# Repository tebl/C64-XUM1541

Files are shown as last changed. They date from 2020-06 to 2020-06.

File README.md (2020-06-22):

# C64 XUM1541

The thing about old 5 1/4 inch floppies is that no matter the way they are stored, they are inherently in a constant decay until they're all disolved into nostalgia and tears. Because of that I wanted to archive my private collection of less than original floppy disks (I didn't know any better and I had a hard time being able to even afford empty disks). Anyway, I came across an interesting [blog-post](https://myoldcomputer.nl/commodore-64/xum1541-promicro/) where a dedicated superfan used an Arduino Pro Micro to connect the drive directly to a modern computer, allowing a disk to be copied to a D64-file within a minute!

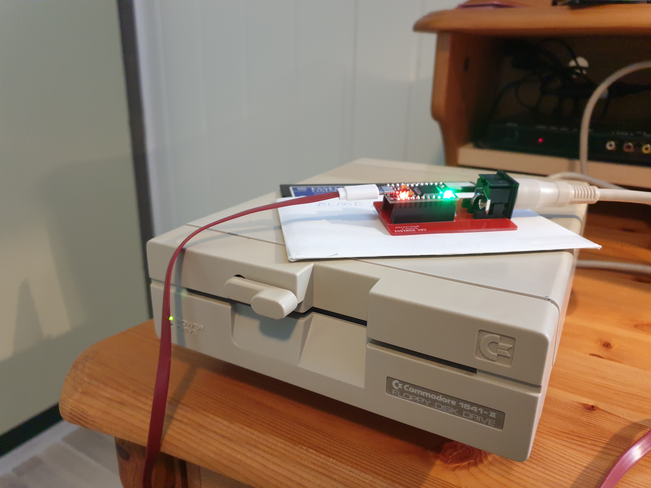
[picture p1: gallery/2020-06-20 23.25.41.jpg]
XUM1541


There are more professional solutions out there with a lot more features, but I wanted the simplest version of it all without actually soldering wires myself - so I threw together a simple PCB with the footprints matching parts I already had laying around in my parts-bin from building my Pi1541 module.

## Building the module
The module only consists of a handful of components, so just enure that get the components matching the BOM listed at the bottom of this page and solder it all together (component counts in parenthesis are not needed for a minimal build). The PCB may seem somewhat oversized for what it is, the reason for this is that I wanted it to fit into one of the 70x45x30mm electronic project boxes - when doing so you'd also install the power LED listed as an optional component, but bent out toward the side so that you can see it inside the box.

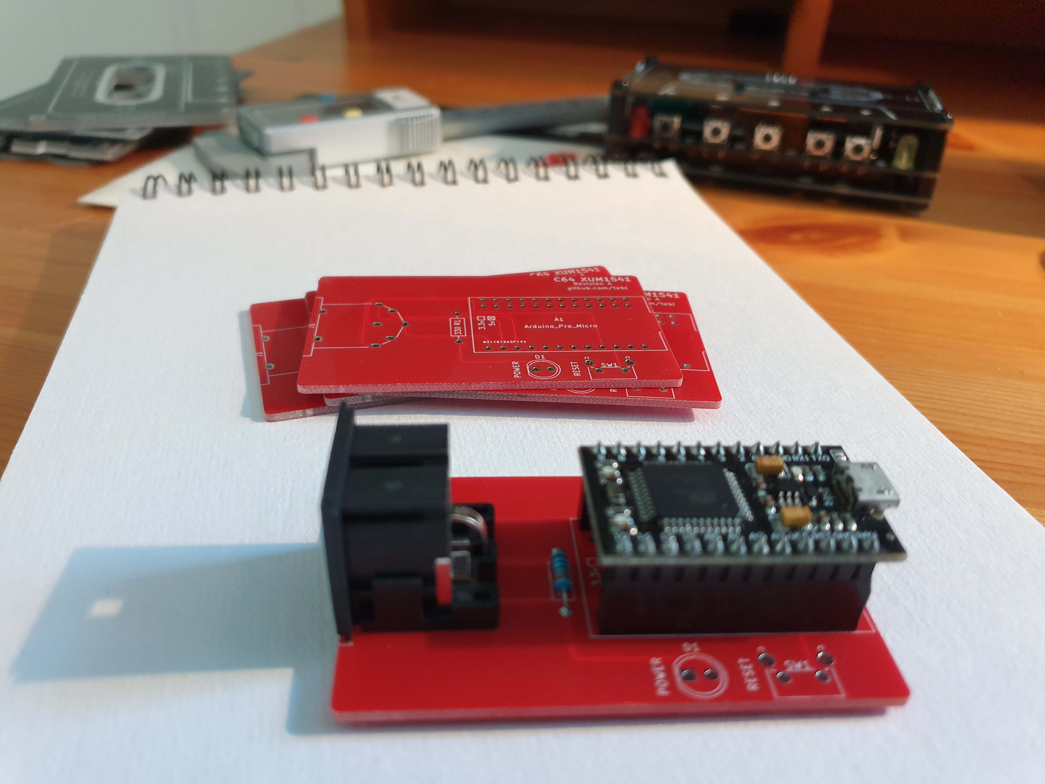
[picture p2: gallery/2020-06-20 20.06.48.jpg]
Module PCB


I you're building more than one of these, you probably won't need to install the reset switch on more than one of them (it is used when initially flashing the Arduino Pro Micro).

## Using the module
Using the actual module is a chapter unto itself, so I've put together a separate [firmware installation document](https://github.com/tebl/C64-XUM1541/blob/master/documentation/firmware.md) describing how to flash the Arduino Pro Micro with the correct firmware as well as set it up with the OpenCBM software for use on a Windows 10 computer. If you're on a different platform, you'll have to look up those guides separately as I only have the one laptop.

There is also an extensive document available that describes the various commands that can be used as part of the [OpenCBM](https://spiro.trikaliotis.net/opencbm#download)-package, this can be found within the install-folder on your computer. With everything working correctly, you're ready to start archiving and for those just wanting to start copying things the command you're looking for is probably the following:
```
d64copy.exe 8 disk.d64
```

**WARNING!** A quick note on the hardware itself is that there is a recommended way of unplugging and plugging in cables, mainly to never do so with the power supplied to it. Commodore 64s and their associated hardware is slowly going extinct like the disks we're trying to archive, so please handle them with the care they deserve!

# Schematic
The supplied KiCad files should be sufficient as both a schematic and as a  starting point for ordering PCBs (basically you could just zip the contents of the export folder and upload that on a fabrication site), the schematic is also available in [PDF-format](https://github.com/tebl/C64-XUM1541/raw/master/documentation/schematic/C64%20XUM1541.pdf) and this is what you'll need to print and work your way through this things don't work as expected after assembly.

# BOM
Most parts should be easy to get a hold of from your favourite local electronic component shop, but given that I don't have access to such shops where I live so everything was based on whatever I could get cheapest from ebay/AliExpress (free shipping, plan on usually waiting 3-4 weeks though). The list below should be everything you'll need in addition to a workable soldering iron and some 60/40 soldering tin.

Any part counts listed in parenthesis are optional, meaning you can skip installing those features if it is a feature you don't want/need. Male pin headers are usually supplied in breakable 40-pin packages, so you'll just use what you need and discard the rest. Installing female pin headers may be preferable as it makes it easier to recover the Arduino Pro Micro for later projects.

| Reference | Item | Count |
| --- | --- | ----- |
| PCB | Fabricate using Gerber files ([order](https://www.pcbway.com/project/shareproject/Commodore_64_XUM1541.html?inviteid=88707)) | 1 |
| A1 | Arduino Pro Micro * | 1 |
| A1 | 12-pin headers | 2 |
| A1 | 12-pin female pin headers | (2) |
| D1 | 5mm LED | (1) | 
| J1 | Female S-terminal 6pin DIN PCB | 1 |
| J2 | 2x8 male pin headers | (1) |
| R1 | 330 ohm resistor | (1) | 
| | 70x45x30mm electronic project box | (1) |
| SW1 | 6x6x5mm right-angle momentary button | 1 |

*) I've purchased a couple of different Arduino Pro Micro boards that had a different physical size, so take care to match up the pins to the PCB so that you solder it up to match the board you own.

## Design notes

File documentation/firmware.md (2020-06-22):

# Firmware installation
The firmware, usually referred to as an Arduino Sketch (though not completely accurate), needed to make the XUM1541 device function needs to be flashed onto the device. It is usually distributed in the form of an Intel Hex-file and depending on the version it would be named something like "xum1541-PROMICRO-v07.hex", it could originally be found as part of the github-page at https://github.com/zyonee/opencbm/tree/master/xum1541. When downloading the file, make sure that you save this file from the raw-format so that you don't get a bunch of html inside it (meaning you shouldn't just right-click it in a browser). I could never get v08 working, so unless that get's fixed I recommend staying with v07.

Check out the mentioned link for complete instructions, but for the quick install notes on doing this from windows - install [WinAVR](https://sourceforge.net/projects/winavr/) (could never get Atmel Flip to function so I skipped that one). This will install a standalone version of the avrdude tools capable of dealing with most microcontrollers.

Finally you'll need to know which COM-port Windows have assigned to your Arduino Pro Micro, so connect it and check out *device manager* and take a look at the Ports-section - the one listed here will probably **NOT** be the one you want! The one you want will only show for 8 seconds after resetting the Pro Micro (press the reset button twice), so keep the window open and reset until you find it.
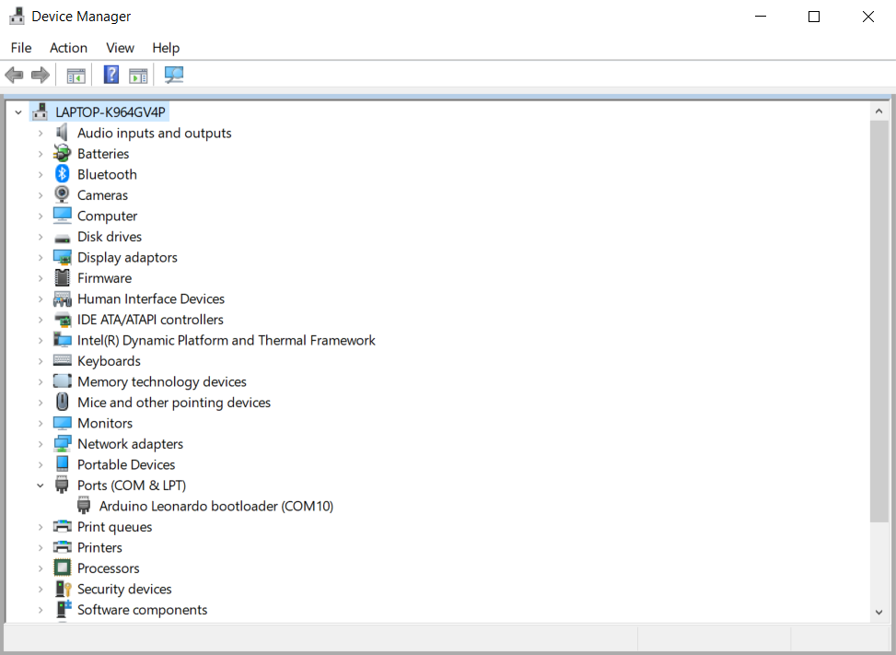
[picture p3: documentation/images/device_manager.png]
device_manager

On my computer the port showed up as com10, so the command used to flash the device before those 8 seconds run out (so reset it again and run the command **before** both LEDs flash).
```
avrdude -p m32u4 -c avr109 -P com10 -U flash:w:xum1541-PROMICRO-v07.hex
```
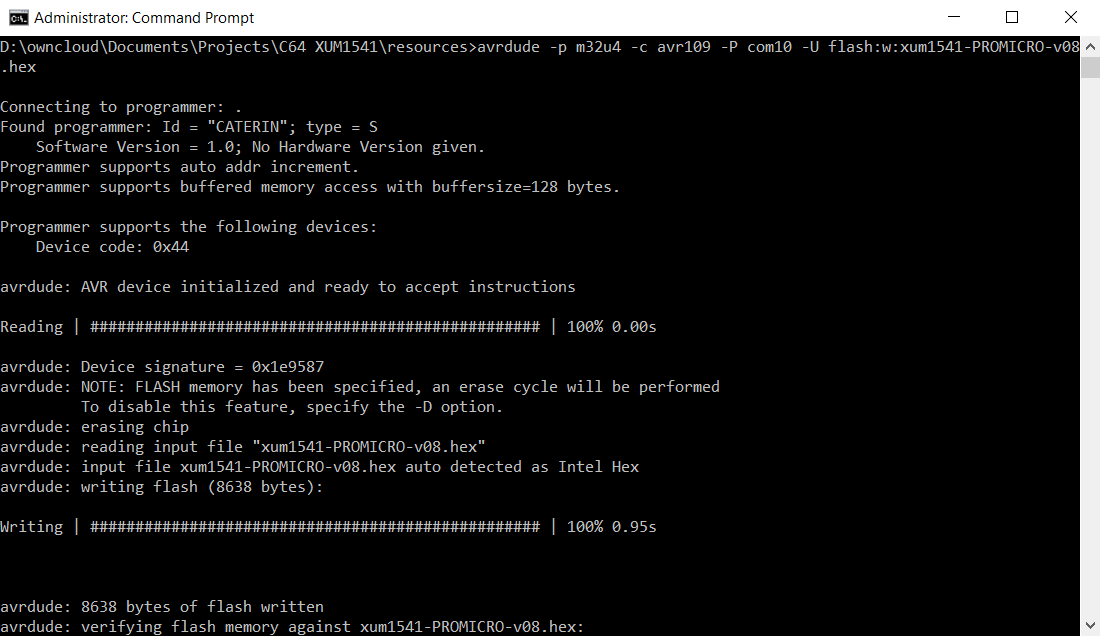
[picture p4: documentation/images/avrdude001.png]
avrdude001

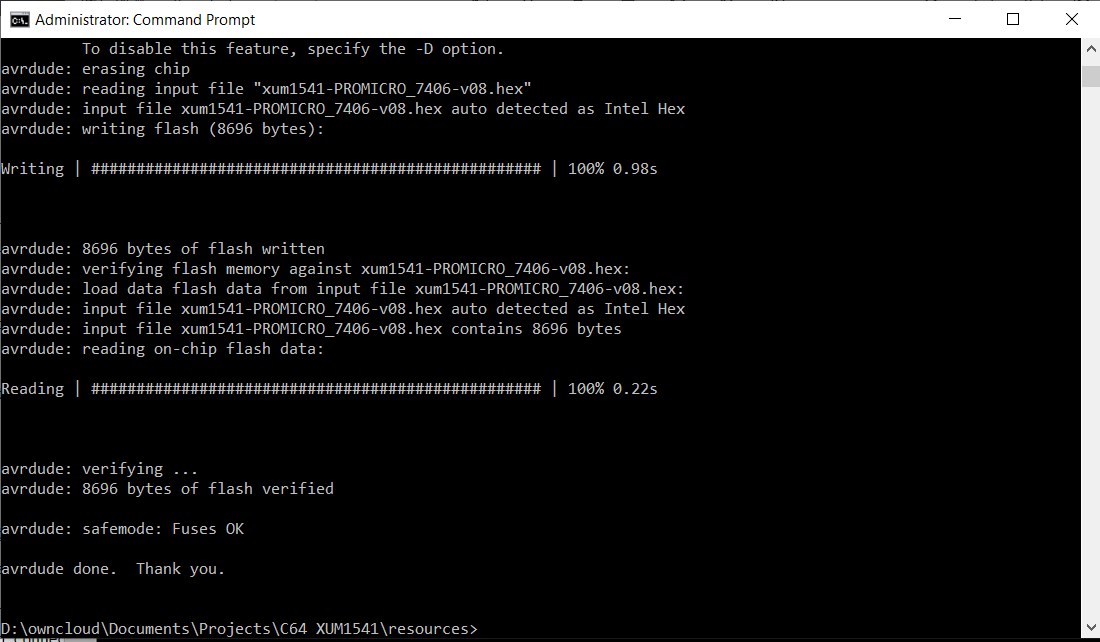
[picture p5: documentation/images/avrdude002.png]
avrdude002

Disconnect and then reconnect the Pro Micro to have the new firmware discovered by Windows, you'll then need to install the USB-driver which is done by using [Zadig](https://zadig.akeo.ie/). List all devices from the *options* dropdown-menu, then locate the XUM1541 device in the device listing. In the target section of the driver selection, click up/down until it says **libusb-win32**. Now you can finally click install/reinstall driver in a form that should hopefully work (refer to picture below if needed).

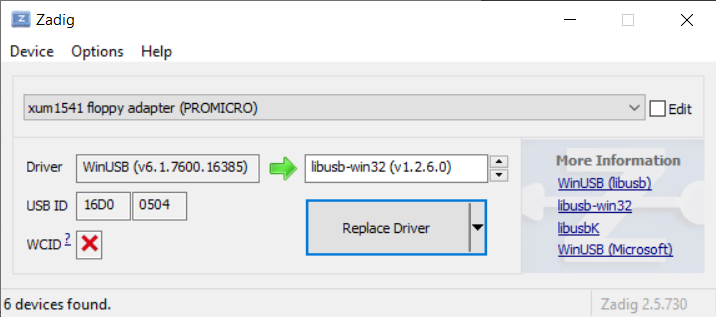
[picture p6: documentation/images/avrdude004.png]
Zadig


**NB!** I could never get version v08 of the firmware to work, so unless that get's fixed I recommend staying with v07 (screenshots were from a failed attempt, so do what I wrote and not what is shown).

# OpenCBM
The actual OpenCBM tools can be downloaded from the creators homepage at [spiro.trikaliotis.net/opencbm](https://spiro.trikaliotis.net/opencbm#download), it's a zip-file and you'll need to extract it to a folder somewhere. Open a CMD-shell in administrator mode, find the directory where you left the extracted file and finally "install" the package by using the following command:
```
install xum1541
```
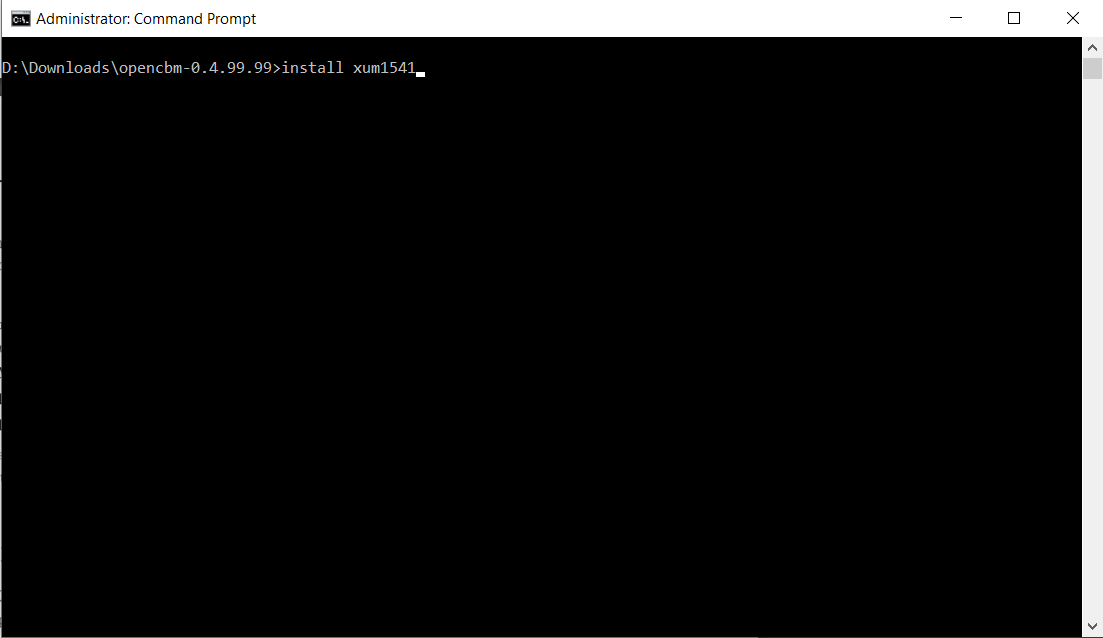
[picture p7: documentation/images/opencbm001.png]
opencbm001

Verify that the module is working by changing your working directory to *C:\Program Files\opencbm* (or something similar, depending on Windows localization). You can now attempt to run some of the commands in order to verify that Windows is able to communicate with the module, for example the following:
```
cbmctrl.exe detect
```
With no 1541 device connected to the module you probably won't get any meaningful feedback, or any at all so in this case no feedback is good news as that means no error messages. With no error messages listed you can now attempt to actually connect a 1541 disk drive (make sure that USB is unplugged when connecting the drive).
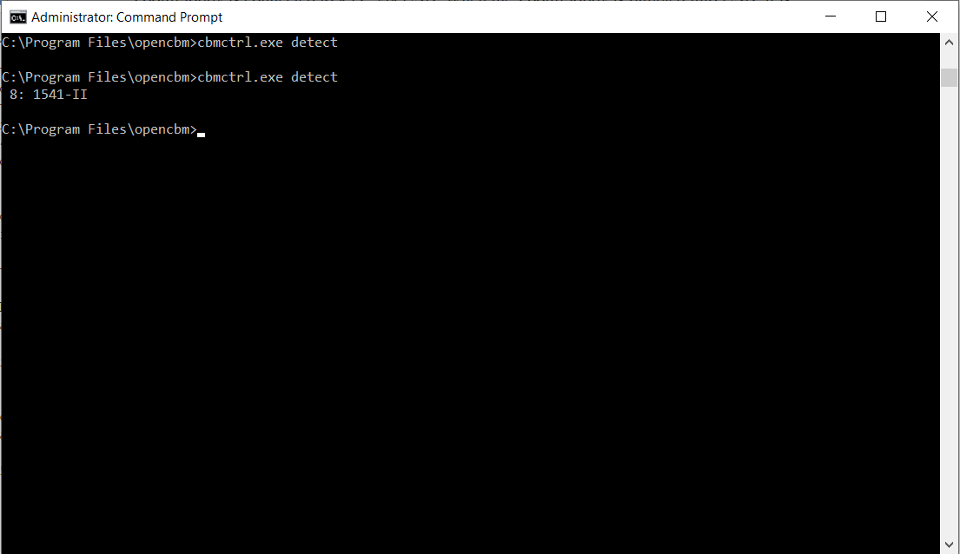
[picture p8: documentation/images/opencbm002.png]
opencbm002

If you bought or built this device, you probably did so with the intention of archiving your own aging floppy disks - so to get you started the command you're probably looking for is the following:
```
d64copy.exe 8 test.d64
```
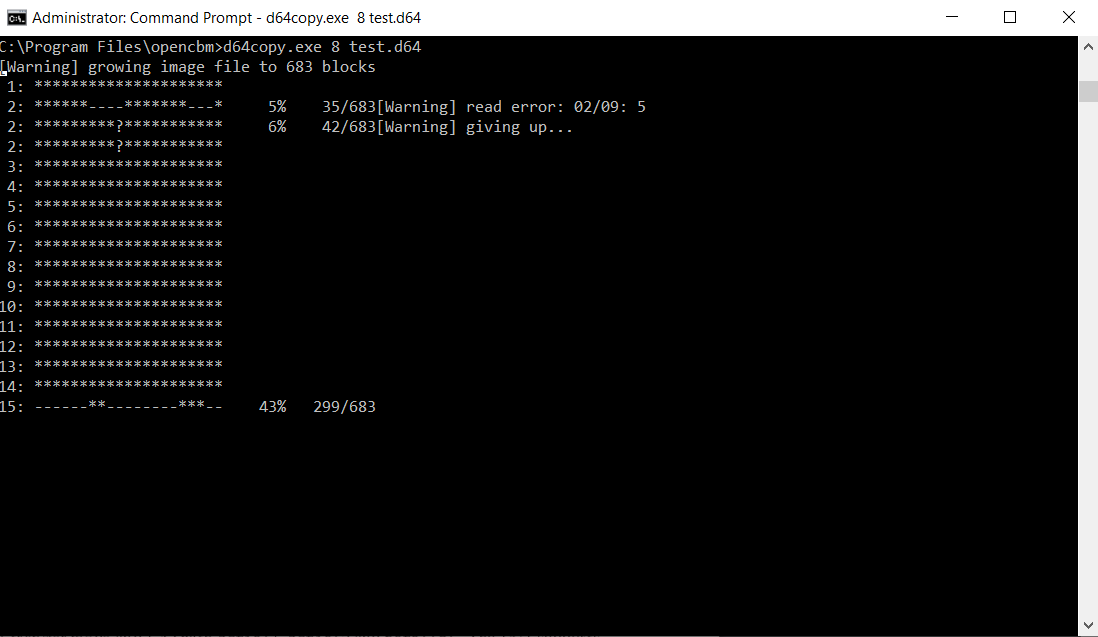
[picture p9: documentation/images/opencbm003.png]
opencbm003

If all goes well, this should make a copy of the disk in drive 8 to a file called *test.d64*. There is a more comprehensive manual that comes with opencbm, it goes into a lot more detail when it comes to describing the various functions that can be performed when using a XUM1541-device.

Given that floppy disks are in a rapid rate of decay, I highly recommend saving the program output to a log file so that you have a record of any errors encountered while dumping the disks (probably can't fix them in any way, but atleast you'll know the disk had errors and don't expect everything to work later). One way of doing this can be as follows (to make things easier I'm using the supplied batch file):
```
d64copy.exe -n 8 "disks\D15B.d64" > "disks\D15B.log" 2>&1
```

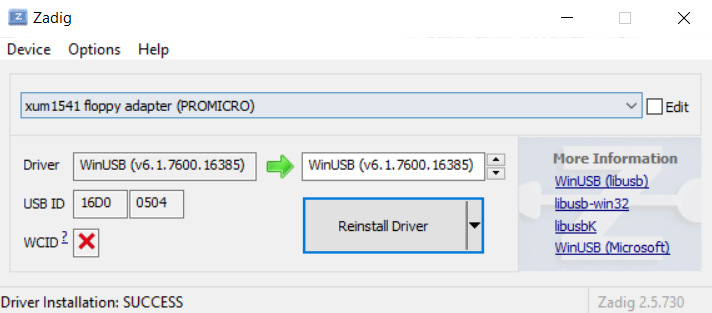
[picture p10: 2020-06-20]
documentation/images/avrdude003.png

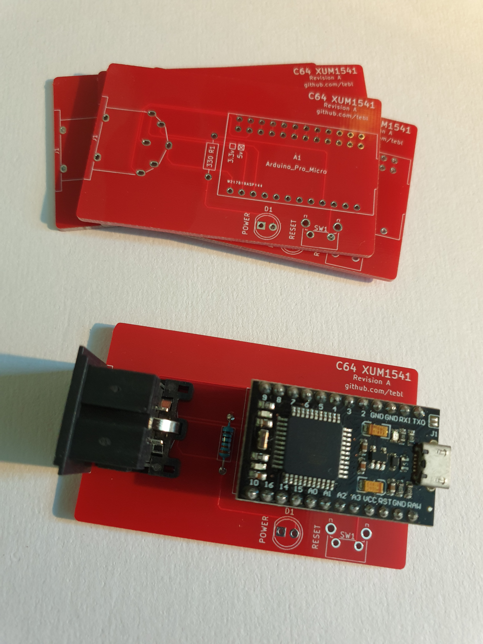
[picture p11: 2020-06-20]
gallery/2020-06-20 20.06.57.jpg

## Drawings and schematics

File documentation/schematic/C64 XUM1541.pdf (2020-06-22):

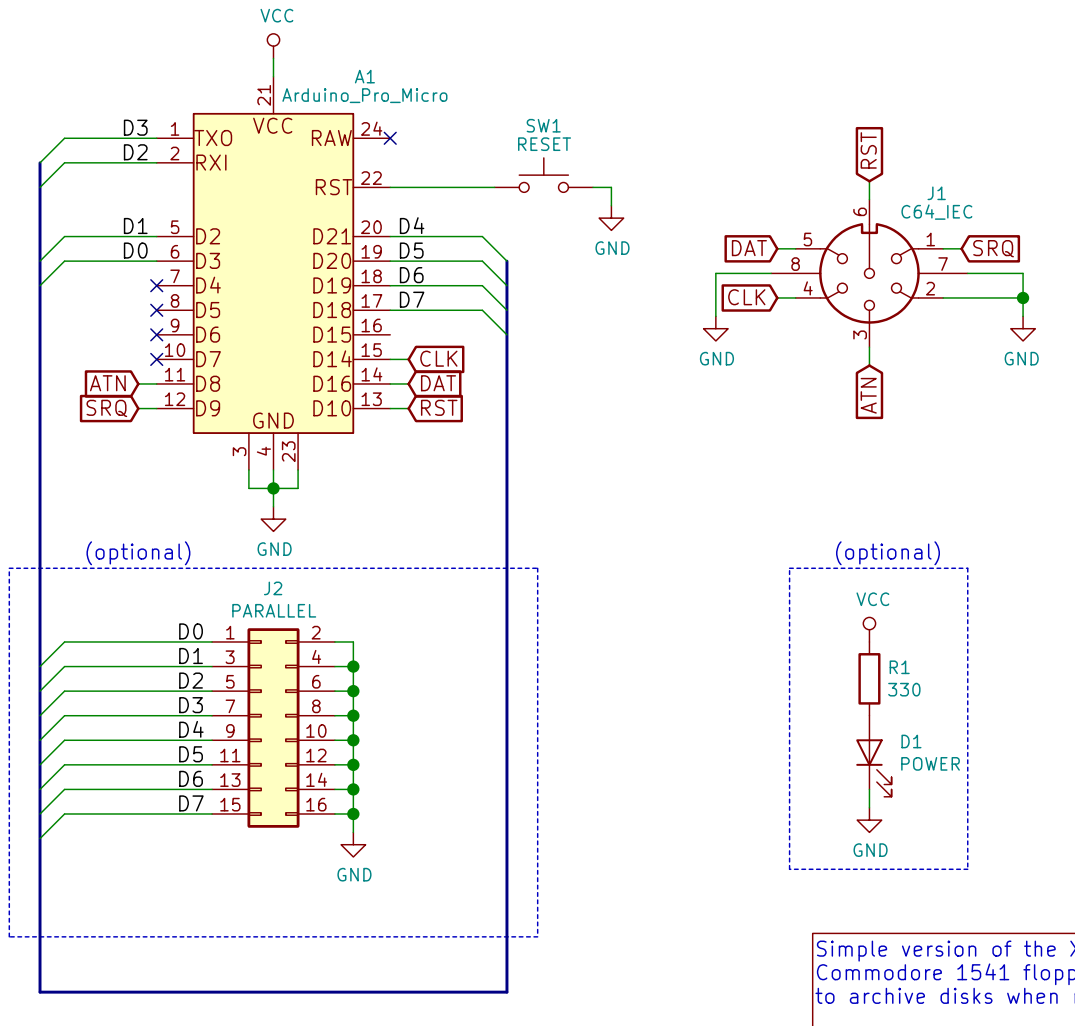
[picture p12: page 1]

Commodore 1541 floppy disk drive from a modern computer. This makes it easy
to archive disks when moving over to PI1541 or something similar.

LED and parallel connectors are optional and not needed for a basic build.

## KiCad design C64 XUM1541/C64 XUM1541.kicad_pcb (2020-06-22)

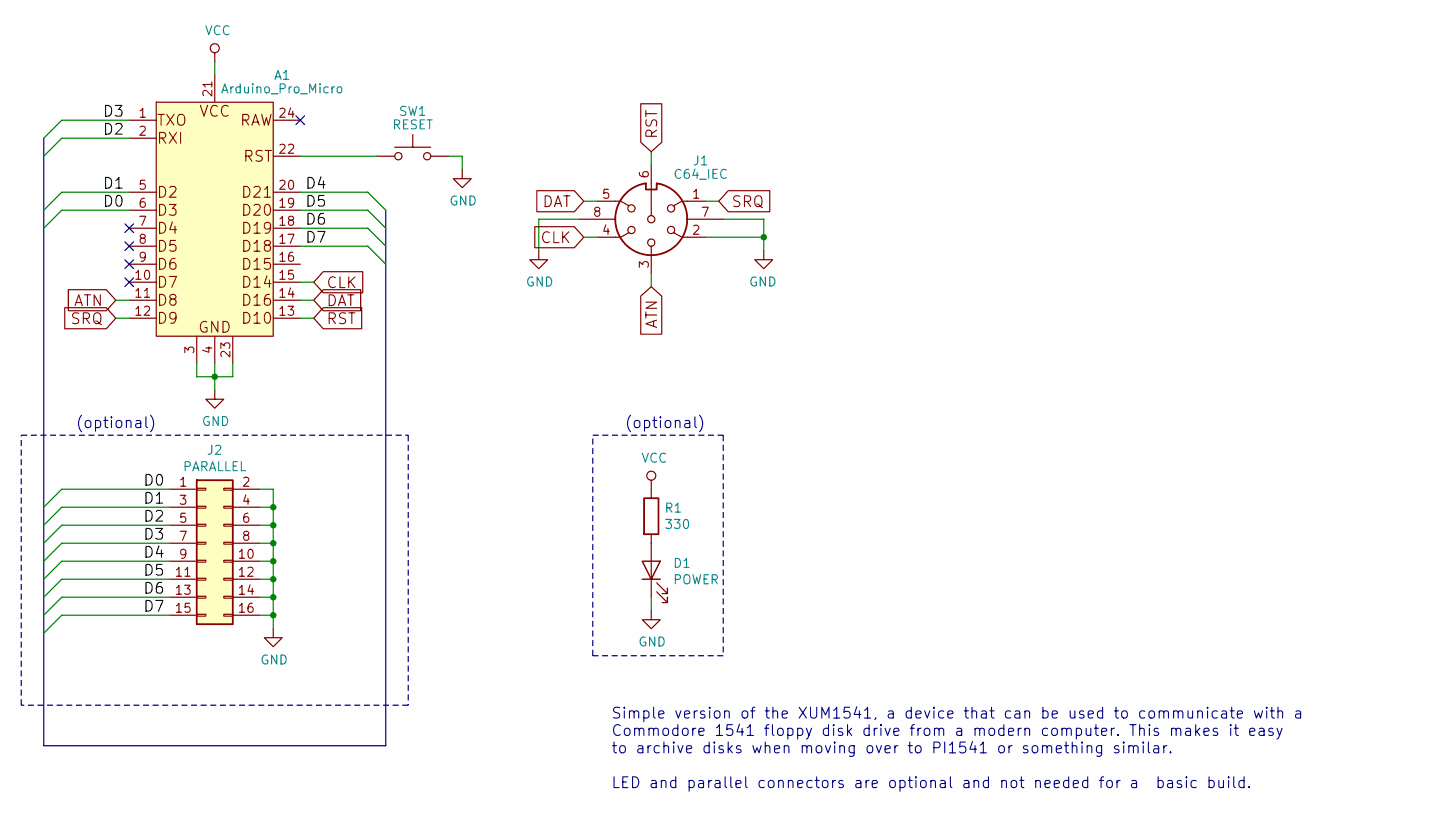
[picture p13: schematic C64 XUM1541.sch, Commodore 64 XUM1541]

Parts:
A1: Arduino_Pro_Micro
D1: POWER; LED_D5.0mm
J1: C64_IEC
J2: PARALLEL; Pin_Header_Straight_2x08_Pitch2.54mm
R1: 330; R_Axial_DIN0207_L6.3mm_D2.5mm_P10.16mm_Horizontal
SW1: RESET; SW_Tactile_SPST_Angled_PTS645Vx39-2LFS

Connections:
/D0: A1.6 (D3), J2.1
/D1: A1.5 (D2), J2.3
/D2: A1.2 (RXI), J2.5
/D3: A1.1 (TXO), J2.7
/D4: A1.20 (D21), J2.9
/D5: A1.19 (D20), J2.11
/D6: A1.18 (D19), J2.13
/D7: A1.17 (D18), J2.15
ATN: A1.11 (D8), J1.3
CLK: A1.15 (D14), J1.4
DAT: A1.14 (D16), J1.5
GND: A1.3 (GND), A1.4 (GND), A1.23 (GND), D1.1 (K), J1.2, J1.7, J1.8, J2.2, J2.4, J2.6, J2.8, J2.10, J2.12, J2.14, J2.16, SW1.2
unnamed: A1.22 (RST), SW1.1
unnamed: D1.2 (A), R1.2
RST: A1.13 (D10), J1.6
SRQ: A1.12 (D9), J1.1
VCC: A1.21 (VCC), R1.1

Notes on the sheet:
Simple version of the XUM1541, a device that can be used to communicate with a Commodore 1541 floppy disk drive from a modern computer. This makes it easy to archive disks when moving over to PI1541 or something similar. LED and parallel connectors are optional and not needed for a basic build.
(optional)

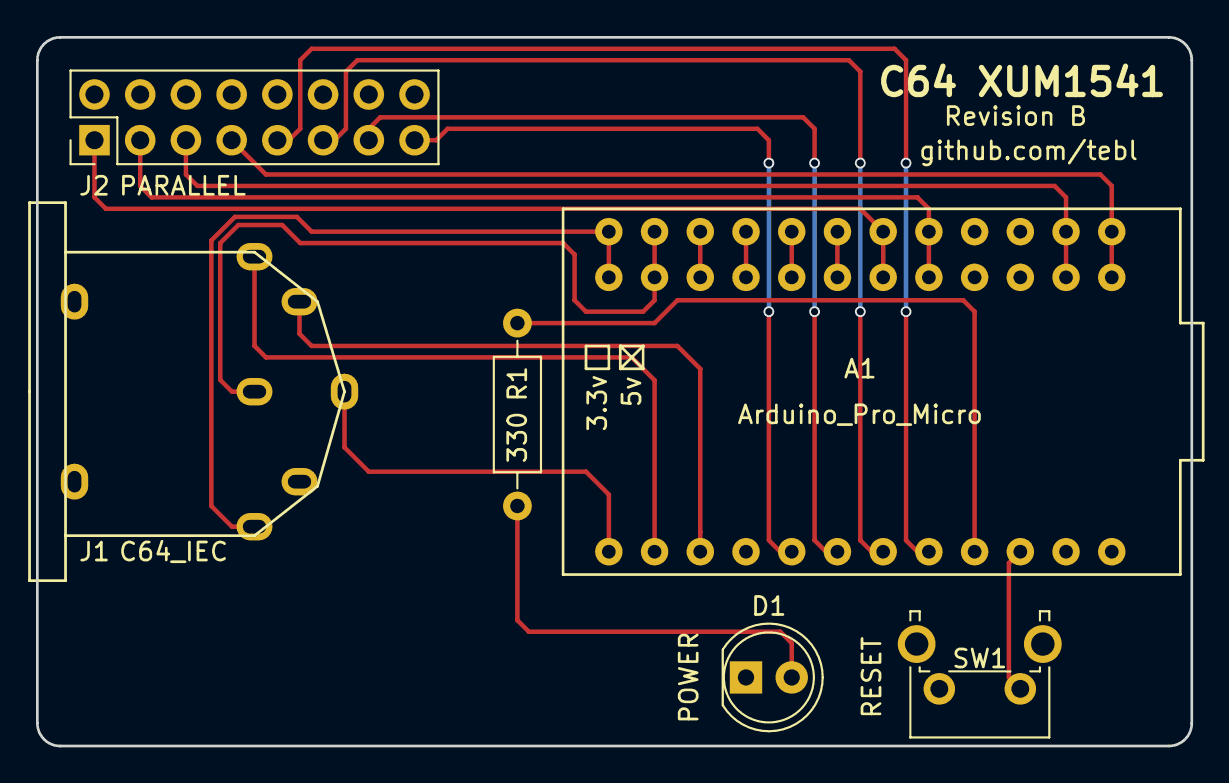
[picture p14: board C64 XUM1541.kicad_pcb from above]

Board: 2 copper layers, 64.1 x 39.4 mm, 6 parts (0 on the bottom side), 17 nets.

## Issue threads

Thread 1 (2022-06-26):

Parallel Port mod for 1541

mamejay, 2022-06-26:
Hello there.  I have made one of these and works perfectly.
I want to add a Parallel port to my 1541 to be able to connect to this XUM1541.
Can you please provide me pinout required on the 6522 chip?  Or is it just the I match up the PA0-7 with the D0-7 on this XUM1541?
Thanks

tebl, 2022-06-26:
Yes, those are the one that need connecting. Note that some drives have pa0
shorted to ground, this needs to be fixed - either by lifting the pin from
a socket, or by cutting the link. You may need to check the internet for
more specific details as I've only owned one disk drive.

søn. 26. jun. 2022, 10:30 skrev mamejay ***@***.***>:

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

mamejay, 2022-06-26:
Perfect!  I did find 64Copy Central site which has much more details regarding connecting to the drive.  I will doctor up a socket and do some testing.

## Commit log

2020-06-07 Bare PCB
    [C64 XUM1541.kicad_pcb, C64 XUM1541.sch]
2020-06-08 Basic module
    [C64 XUM1541-B_Cu.gbl, C64 XUM1541-B_Mask.gbs, C64 XUM1541-B_Paste.gbp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]
2020-06-22 Added parallel header
    [C64 XUM1541-B_Cu.gbl, C64 XUM1541-B_Mask.gbs, C64 XUM1541-B_Paste.gbp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]
2020-06-22 Update link to schematic
